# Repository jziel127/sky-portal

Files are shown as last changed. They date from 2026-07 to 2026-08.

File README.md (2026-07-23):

# Sky Portal — Automated Circadian Lighting & Clock

A personal engineering project that adds automation and a companion display to a [Chroma Sky Portal 2.1](https://getchroma.co/) circadian light — without modifying the light itself.

## What it does

- **Automates the Sky Portal's settings** (brightness/"Photon" and color temperature/"Red-White Ratio") throughout the day, driven by real solar and weather data rather than a physical light sensor. Small external servos physically turn the light's existing knobs, so the device itself is never opened or altered.
- **Auto power on/off** via a third, higher-torque servo that physically flips the unit's power switch.
- **A companion 16x16 LED matrix** running [WLED](https://kno.wled.ge/) on an ESP32 shows a clock, the date, and the current outdoor weather (with a simple animated icon and temperature), cycling automatically.

## How it works (high level)

```
Windows mini PC (central brain)
   │  pulls solar elevation + cloud cover from OpenWeatherMap
   │  computes a "circadian phase" for the day
   │
   ├── USB Serial ──► Arduino Pro Mini ──► 3 servos (Photon, Color Ratio, Power)
   │
   └── HTTP/MQTT ──► ESP32 (WLED) ──► 16x16 LED matrix (clock + weather display)
```

## Hardware

- Chroma Sky Portal 2.1 (the light being automated)
- Windows mini PC (GMK NucBox5) — control logic, API calls
- Arduino Pro Mini + FTDI adapter — servo control
- 2x SG90 micro servos + 1x MG996R servo
- ESP32 + WS2812B 16x16 LED matrix, running WLED
- Custom 3D-printed enclosure housing the electronics, attached to the light's stand

## Status

Actively in progress — the LED matrix clock is fully built and running; the servo/knob automation is the current phase of work.

## Why this project exists

Built as a personal engineering/robotics project to combine embedded systems, API integration, and mechanical design into something used every day — not a commercial product, and not affiliated with Chroma.

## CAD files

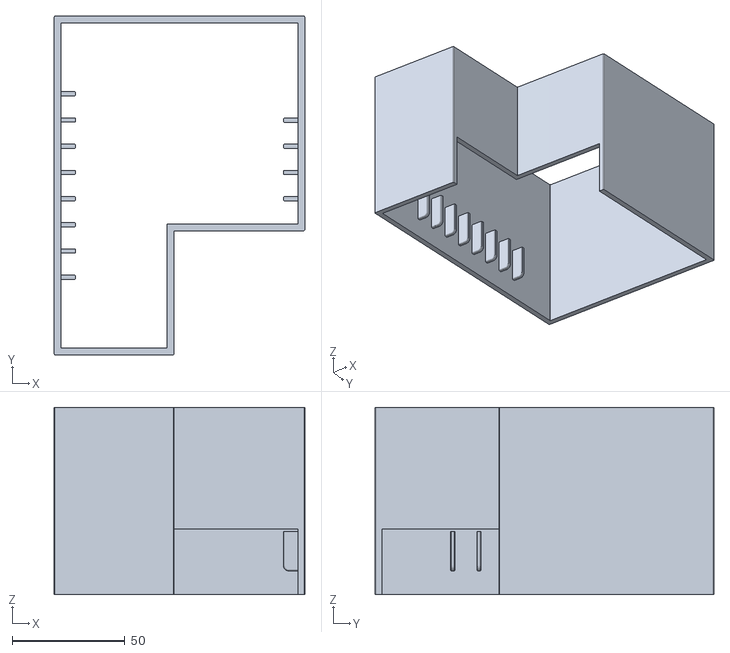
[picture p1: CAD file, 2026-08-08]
3D Models/SkyPortal Outer Case.stl
111.0 x 150.2 x 83.0

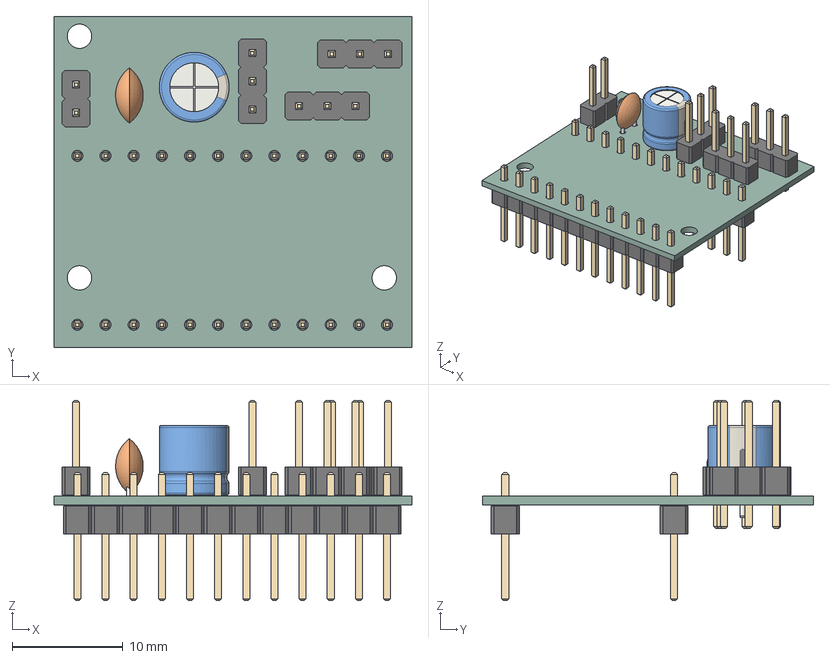
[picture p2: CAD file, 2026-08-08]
Motor PCB/MotorPCB.step
32.3 x 29.9 x 18.1 mm
CP_Radial_D63mm_P250mm
PinHeader_1x03_P254mm_Vertical x 3
PinHeader_1x02_P254mm_Vertical
C_Disc_D50mm_W25mm_P250mm
PinHeader_1x12_P254mm_Vertical x 2
Motor PCB_PCB

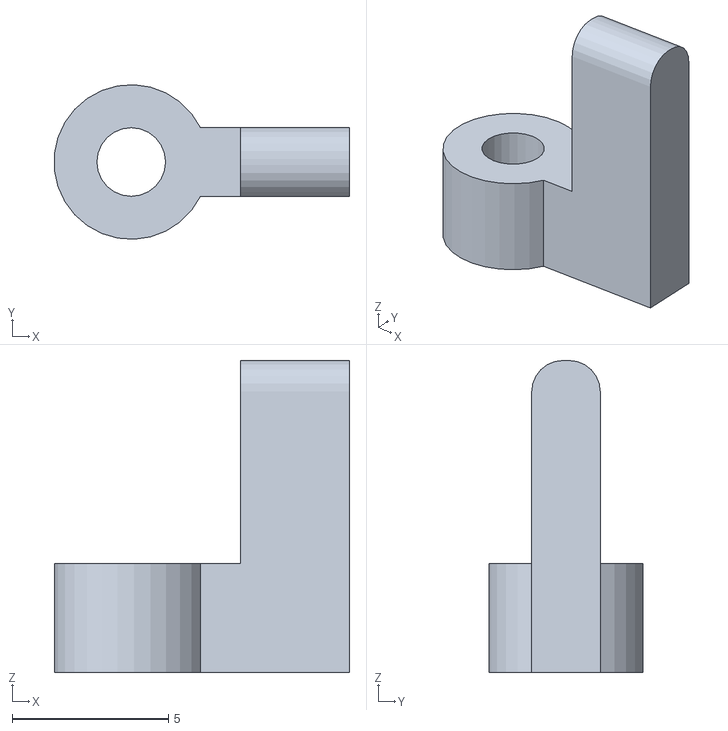
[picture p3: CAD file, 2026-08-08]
3D Models/Servo_LSmodv3.stl
9.46 x 4.95 x 10.00

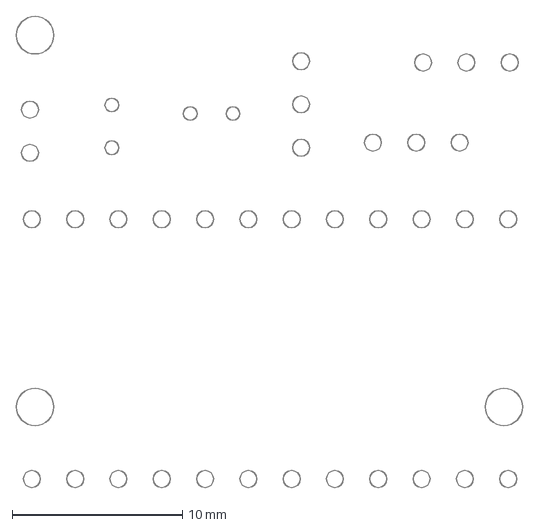
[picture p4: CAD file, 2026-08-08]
Motor PCB/Motor PCB-User_Drawings.dxf
29.7 x 27.6 mm

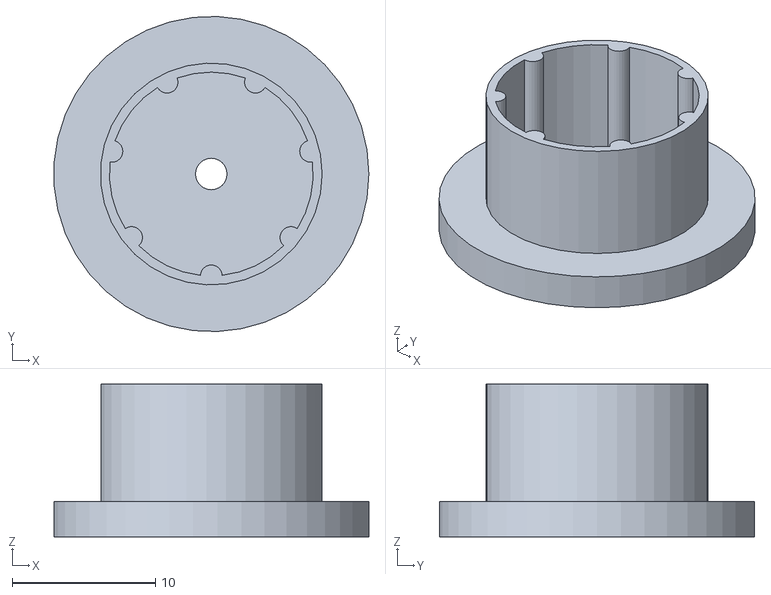
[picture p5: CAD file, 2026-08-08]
3D Models/POT_mod.STL
22.0 x 22.0 x 10.7

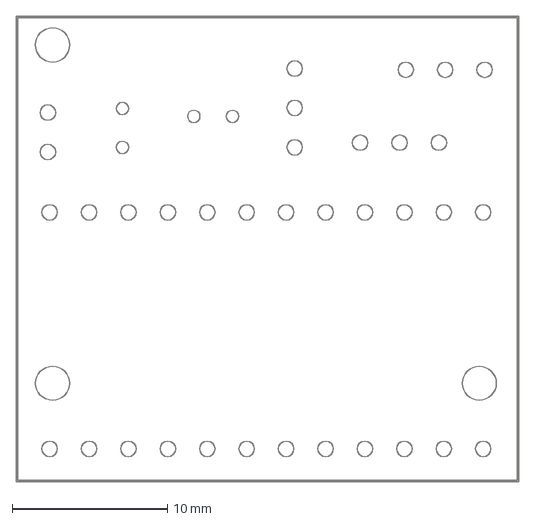
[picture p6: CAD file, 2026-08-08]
Motor PCB/Motor PCB-Edge_Cuts.dxf
32.4 x 30.0 mm

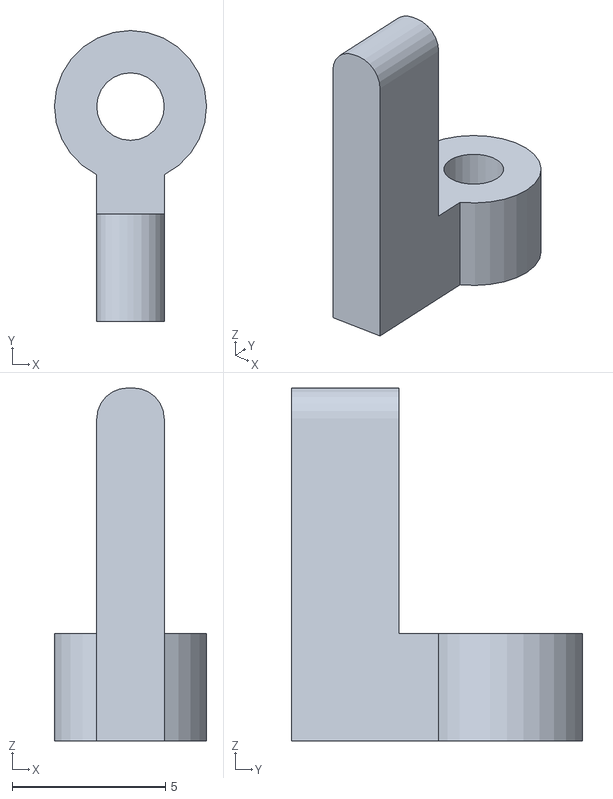
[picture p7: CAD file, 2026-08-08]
3D Models/Servo_LSmodv2.stl
4.95 x 9.48 x 11.5

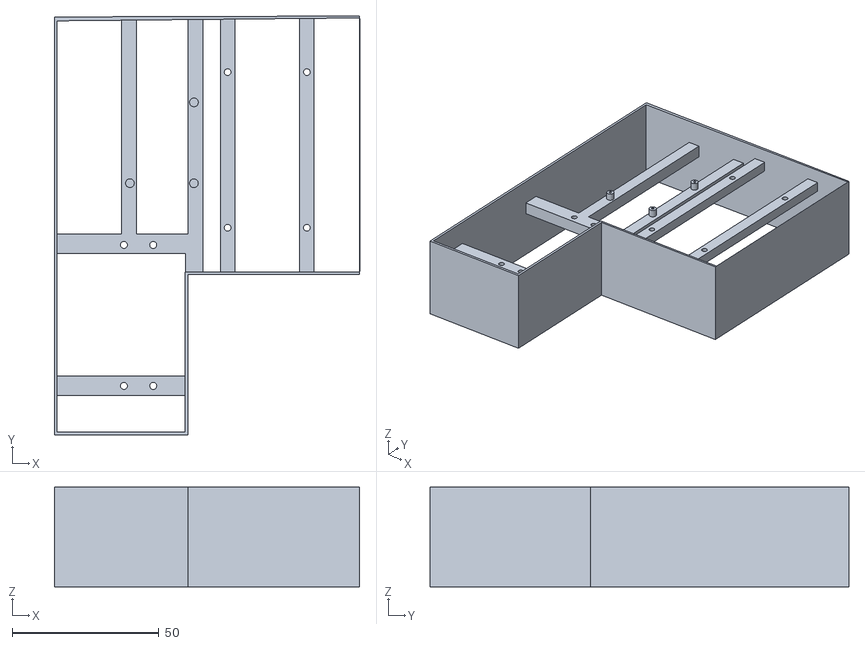
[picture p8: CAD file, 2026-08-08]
3D Models/SkyPortal Bracket.stl
104.0 x 142.7 x 34.0

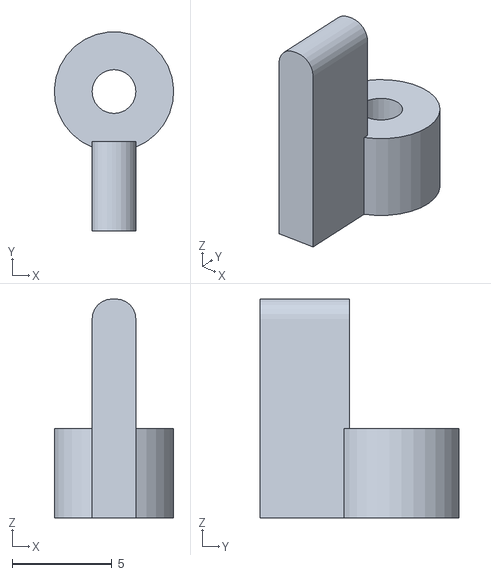
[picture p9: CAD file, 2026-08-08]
3D Models/Servo_LSmodv4.stl
6.00 x 9.98 x 11.0

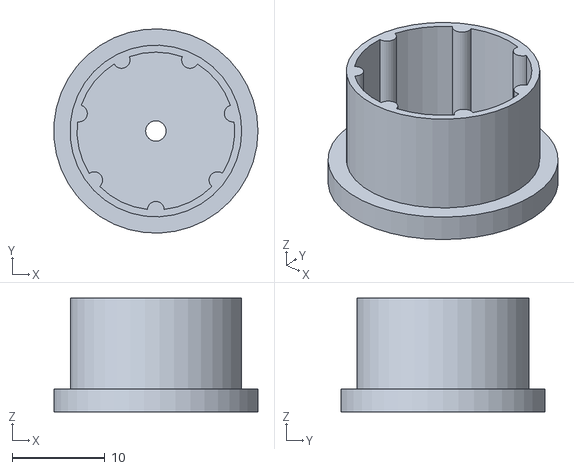
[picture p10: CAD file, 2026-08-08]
3D Models/Servo_POTmod.stl
22.0 x 22.0 x 12.3

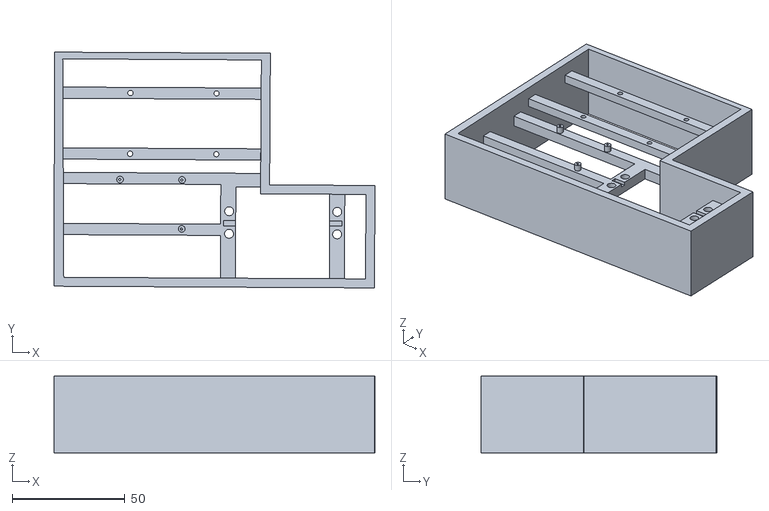
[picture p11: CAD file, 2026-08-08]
3D Models/SkyPortal PCBracket v2.stl
142.6 x 104.7 x 34.0

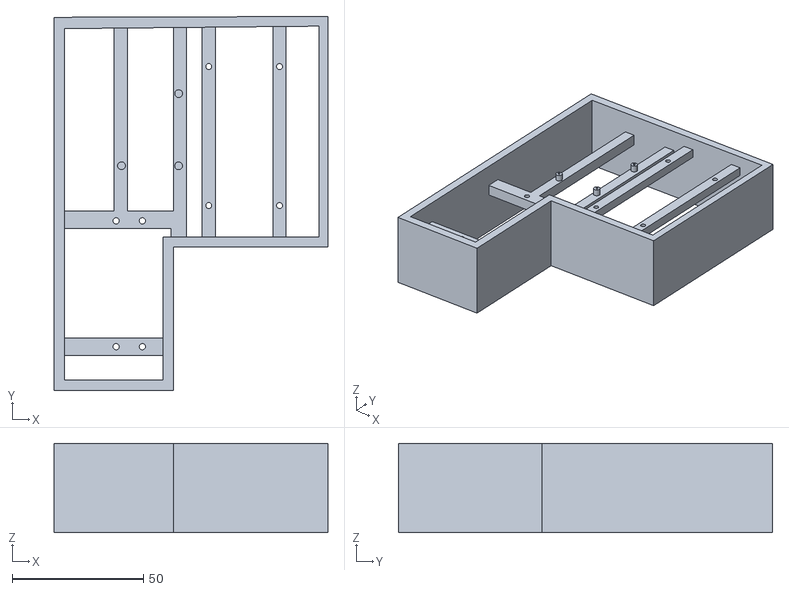
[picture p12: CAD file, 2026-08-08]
3D Models/SkyPortal Bracket v2.stl
104.5 x 142.7 x 34.0

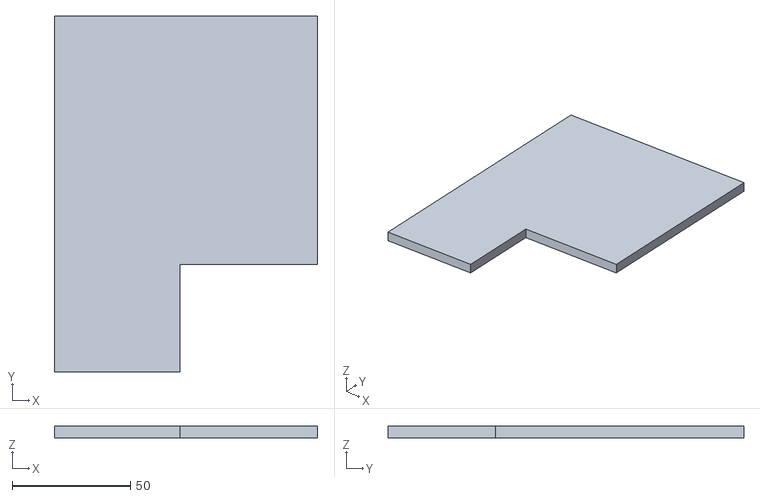
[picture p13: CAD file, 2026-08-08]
3D Models/SkyPortal cover.stl
111.1 x 150.3 x 5.00

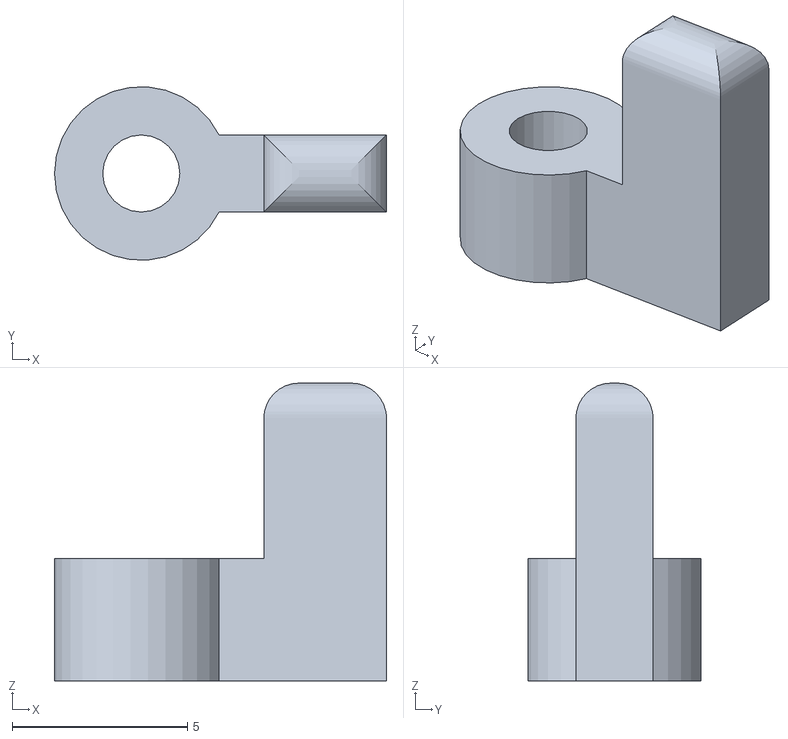
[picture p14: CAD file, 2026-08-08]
3D Models/Servo_LSmod.stl
9.48 x 4.94 x 8.50

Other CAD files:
3D Models/SkyPortal Case.dwg
3D Models/SkyPortal OuterCasev2.stl
3D Models/Servo_LSmod.dwg
3D Models/Servo_POTmod.dwg

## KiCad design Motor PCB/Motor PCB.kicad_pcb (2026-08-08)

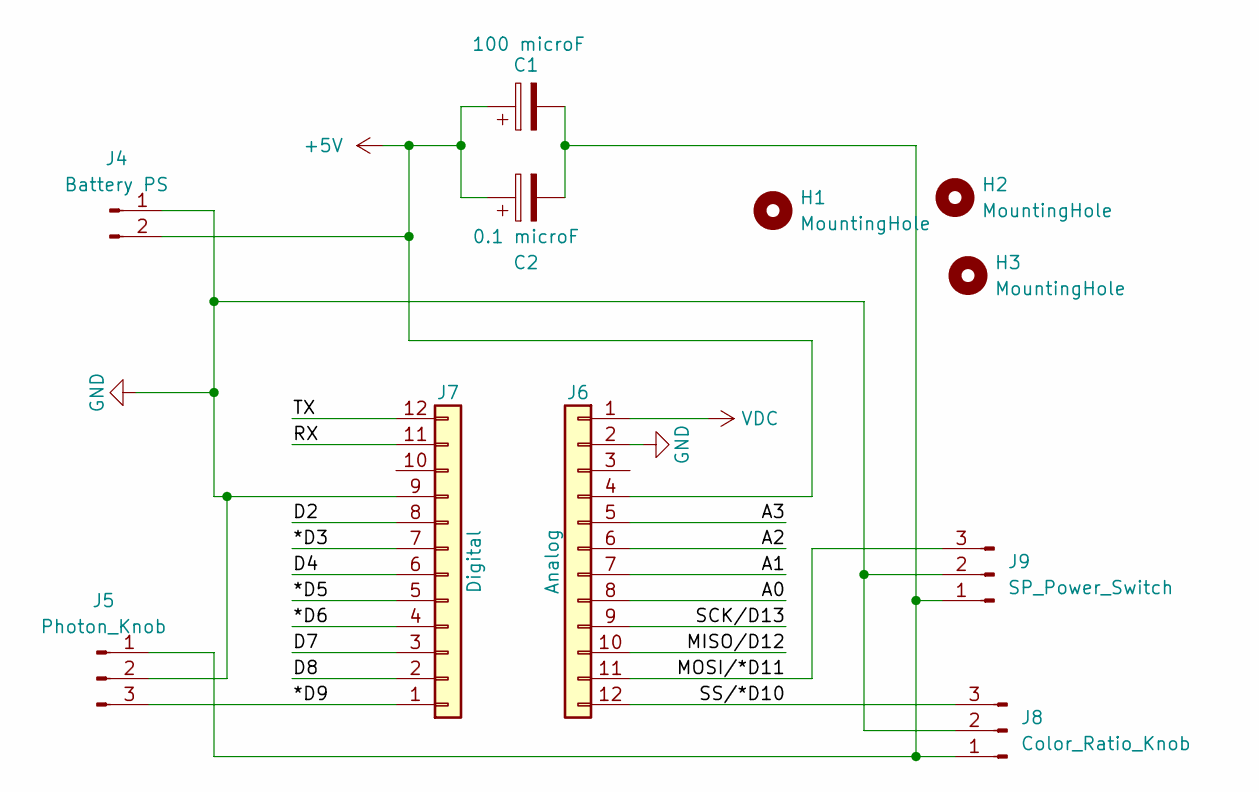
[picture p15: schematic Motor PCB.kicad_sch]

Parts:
C1: 100 microF; CP_Radial_D6.3mm_P2.50mm
C2: 0.1 microF; C_Disc_D5.0mm_W2.5mm_P2.50mm
H1, H2, H3: MountingHole; MountingHole_2.2mm_M2
J4: Battery PS; PinHeader_1x02_P2.54mm_Vertical
J5: Photon_Knob; PinHeader_1x03_P2.54mm_Vertical
J6: Analog; PinHeader_1x12_P2.54mm_Vertical
J7: Digital; PinHeader_1x12_P2.54mm_Vertical
J8: Color_Ratio_Knob; PinHeader_1x03_P2.54mm_Vertical
J9: SP_Power_Switch; PinHeader_1x03_P2.54mm_Vertical

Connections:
+5V: C1.1, C2.1, J4.2, J6.4
/*D3: J7.7
/*D5: J7.5
/*D6: J7.4
/*D9: J5.3, J7.1
/A0: J6.8
/A1: J6.7
/A2: J6.6
/A3: J6.5
/D2: J7.8
/D4: J7.6
/D7: J7.3
/D8: J7.2
/MISO/D12: J6.10
/MOSI/*D11: J6.11, J9.3
/RX: J7.11
/SCK/D13: J6.9
/SS/*D10: J6.12, J8.3
/TX: J7.12
GND: J4.1, J5.2, J6.2, J7.9, J8.2, J9.2
unnamed: C1.2, C2.2, J5.1, J8.1, J9.1
VDC: J6.1

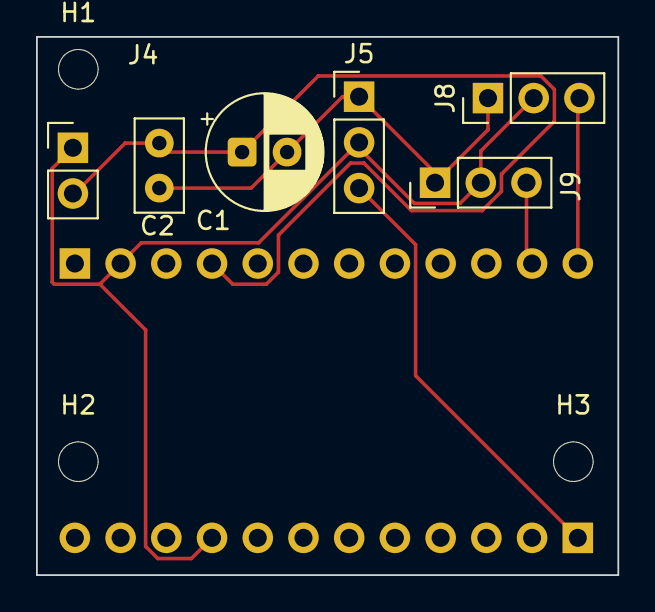
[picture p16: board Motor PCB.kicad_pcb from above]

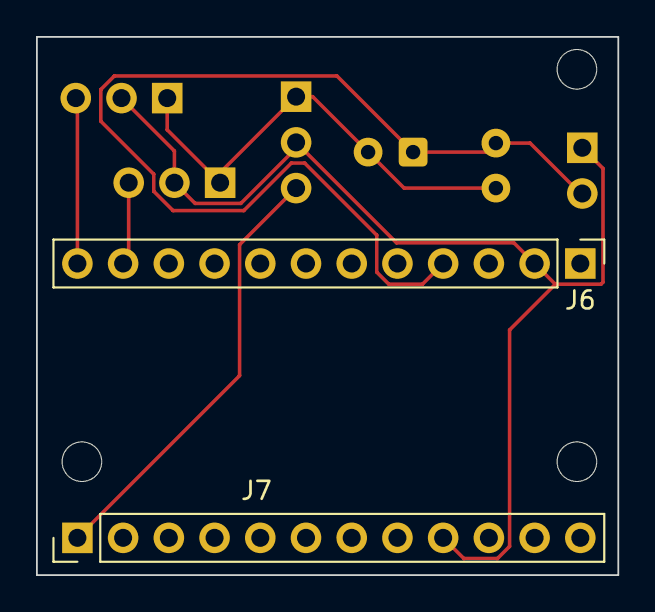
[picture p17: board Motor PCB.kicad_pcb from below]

Board: 2 copper layers, 32.3 x 29.9 mm, 11 parts (2 on the bottom side), 6 nets.

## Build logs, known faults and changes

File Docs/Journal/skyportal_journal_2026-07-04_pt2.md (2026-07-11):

# Sky Portal Project — Journal Entry (Part 2)
**Date:** July 4, 2026 (continued)
**Session focus:** Architecture simplification (weather-API-driven, no physical light sensor), WLED/ESP32 decision, comprehensive status check

---

## Major Architecture Decision: No Physical Light Sensor

**Change:** Dropped the BH1750 ambient light sensor and the Pico W's role as a wireless sensor node. Circadian logic will be driven **entirely by OpenWeatherMap API data** (solar elevation, cloud cover, UV index) rather than fused with real-world lux readings.

**Why:** Simpler build, no sensor hardware to buy/mount near a window, one less wireless node to maintain.

**What this eliminates:**
- BH1750 sensor (no longer needed)
- Pico W's original job (reading BH1750, publishing lux over MQTT) — no longer needed
- Sensor fusion logic in the circadian-phase calculation — simplified to weather-data-only

**What survives from that work:**
- Mosquitto broker — kept running, will be used for the future tablet control panel (final project phase)
- Pico W hardware itself — currently idle, may be repurposed (see WLED/ESP32 section below)
- All infrastructure debugging from today (static IP, Python env, VS Code/MicroPico, Mega serial) — general-purpose, not wasted

---

## WLED / ESP32 Decision (LED Matrix Control)

**Trigger:** Found a YouTube video ("16x16 LED Matrix Setup with WLED and ESP32, BEST Enclosure Design") demonstrating WLED firmware + ESP32 + a 3D-printed enclosure for a 16x16 WS2812B matrix — directly applicable to the Sky Portal desk display.

**Investigated:** Whether the already-owned Raspberry Pi Pico W could run WLED instead of buying new hardware.

**Finding:** WLED does **not** officially support the Pico W / RP2040 chip. Two separate feature requests for RP2040 support were formally closed by WLED maintainers as "not planned." WLED is built specifically for ESP8266/ESP32 (Espressif) chips.

**Decision:** Acquired the same ESP32 board used in the referenced video, specifically to run WLED for the LED matrix. Pico W remains idle/unused for now (available for future repurposing if needed).

### Updated Hardware Roles

| Component | Role |
|---|---|
| Windows Mini PC (NucBox5) | Central brain — OpenWeatherMap API calls, circadian phase calculation, sends commands via serial (to Mega) and MQTT/HTTP (to WLED on ESP32) |
| ESP32 (new) | Runs WLED firmware, drives the WS2812B 16x16 matrix, controlled via WLED's built-in JSON API / MQTT |
| Elegoo Mega 2560 | Drives the 2x SG90 servos (Sky Portal knob control) via USB serial from the mini PC — confirmed working (Leg 2 test) |
| Raspberry Pi Pico W | Currently idle — MQTT pipeline proven working, could be repurposed later if a wireless sensor or other node is ever added back |
| Mosquitto (on mini PC) | Broker kept running — reserved for future tablet control panel (final phase) and potentially for WLED's MQTT interface |

### Revised Data Flow

```
[Windows Mini PC — NucBox5]
    │ OpenWeatherMap API → circadian phase calculation
    │
    ├── USB Serial (pyserial) ──→ Elegoo Mega 2560 ──→ 2x SG90 servos ──→ Sky Portal knobs
    │
    └── MQTT / HTTP JSON API ──→ ESP32 (WLED) ──→ WS2812B 16x16 matrix
```

---

## Physical Build Status

- **3D printing in progress** for enclosure/mounting parts (following the design referenced in the WLED video) — estimated **~1 more day** until all parts are done
- **Known issue flagged:** trouble with the **back plate** during printing — not yet resolved/detailed; to be revisited if it recurs. Noting here so it isn't lost track of.

---

## Comprehensive Status Check — All Systems

| System | Status | Notes |
|---|---|---|
| Windows Mini PC networking | ✅ Done | Static IP `192.168.1.222`, gateway `192.168.1.254`, DNS `8.8.8.8`/`1.1.1.1`, Private network profile confirmed |
| Python environment | ✅ Done | Installed and working after installer/service hiccups |
| Mosquitto broker | ✅ Done | Listening on `0.0.0.0:1883` (fixed from localhost-only), firewall rule allowed, service confirmed running |
| VS Code + MicroPico | ✅ Done | Extension installed, Pico W firmware flashed, vREPL working |
| Arduino IDE + Mega 2560 | ✅ Done | Flashed, serial confirmed on COM3 |
| **Leg 1: Mosquitto loopback** | ✅ Confirmed | pub/sub tested locally |
| **Leg 2: Mega ↔ Python serial** | ✅ Confirmed | LED_ON test successful — this is the leg that matters going forward (servo control) |
| **Leg 3: Pico W → MQTT** | ✅ Confirmed | Full Wi-Fi → broker → subscriber chain validated (0–12 counter test) — pipeline proven, though Pico W's original job (sensor) is no longer part of the plan |
| BH1750 sensor | ❌ Not used | Architecture decision — using weather API instead |
| Circadian-phase Python script | ⬜ Not started | Next major software task |
| Mega servo control sketch | ⬜ Not started | Replace LED test sketch with real SG90 PWM code |
| ESP32 + WLED setup | ⬜ Not started | New hardware just acquired |
| Windows Scheduled Task | ⬜ Deferred | Waiting until control script exists |
| Tablet control panel | 🔜 Final phase | Explicitly deferred until core automation is finished; budget tablet options already researched (Fire HD 8, Galaxy Tab A8/A9, Lenovo Tab M10/M11) |

---

## To-Do List — Next Moves

### Immediate (while waiting on 3D prints, ~1 day)
1. [ ] Set up OpenWeatherMap API account/key if not already done
2. [ ] Flash WLED firmware onto the new ESP32 (via WLED's web installer or esptool)
3. [ ] Confirm ESP32 connects to Wi-Fi and WLED's web UI is reachable
4. [ ] Test WLED's JSON API / MQTT interface with simple manual commands (set color, brightness) before writing any control code
5. [ ] Revisit the back plate 3D print issue if it recurs — flag specifics (warping, layer separation, fitment, etc.) once seen again

### Once 3D prints are done
6. [ ] Physically mount ESP32 + WS2812B matrix using the printed enclosure
7. [ ] Mount SG90 servos onto Sky Portal knobs (Photon + Red/White Ratio)

### Core software build (can start in parallel with printing)
8. [ ] Write the circadian-phase Python script on the mini PC:
   - Pull solar elevation, cloud cover, UV index from OpenWeatherMap
   - Convert to photon level (0–100%) and color-temp ratio (0–100%)
9. [ ] Write the real Mega sketch: replace LED test code with SG90 servo PWM control, driven by serial commands from the Python script
10. [ ] Write the WLED control layer: Python script sends JSON API or MQTT commands to the ESP32 to update matrix color/brightness in sync with circadian phase
11. [ ] Integrate all three pieces into one continuous control loop on the mini PC
12. [ ] Set up the Windows Scheduled Task to run the finished script automatically at startup

### Final phase (explicitly deferred)
13. [ ] Tablet control panel — build a simple web dashboard (Flask or similar) for manual override, served from the mini PC, controlled via MQTT; select tablet hardware from previously researched options

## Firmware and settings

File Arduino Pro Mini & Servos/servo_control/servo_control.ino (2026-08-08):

#include <Servo.h>
#include <EEPROM.h>

// --- PCB PIN DEFINITIONS ---
const int PIN_PHOTON       = 9;   // J5 Header
const int PIN_COLOR_RATIO  = 10;  // J8 Header
const int PIN_POWER_SWITCH = 11;  // J9 Header

// --- EEPROM ADDRESSES ---
const int ADDR_PHOTON       = 0;
const int ADDR_COLOR_RATIO  = 2;
const int ADDR_POWER_SWITCH = 4;
const int ADDR_MAGIC        = 6;  // Marker to check if EEPROM is initialized
const uint16_t EEPROM_MAGIC = 0xABCD;

// --- SERVO OBJECTS & STATE ---
Servo photonServo;
Servo colorRatioServo;
Servo powerServo;

int targetPhoton     = 0;   // 0 (Max Red) to 180 (White)
int targetColorRatio = 0;   // 0 (Low) to 180 (High)
int targetPower      = 0;   // 0 (OFF) to 180 (ON)

int currentPhoton     = 0;
int currentColorRatio = 0;
int currentPower      = 0;

// --- HELPER: SMOOTH MOTION ENGINE ---
// Moves servos incrementally to eliminate harsh mechanical snaps and current spikes
void moveServosSmoothly() {
  bool moving = true;
  while (moving) {
    moving = false;

    // Photon Knob
    if (currentPhoton < targetPhoton) { currentPhoton++; moving = true; }
    else if (currentPhoton > targetPhoton) { currentPhoton--; moving = true; }
    photonServo.write(currentPhoton);

    // Color Ratio Knob
    if (currentColorRatio < targetColorRatio) { currentColorRatio++; moving = true; }
    else if (currentColorRatio > targetColorRatio) { currentColorRatio--; moving = true; }
    colorRatioServo.write(currentColorRatio);

    // Light Power Switch
    if (currentPower < targetPower) { currentPower++; moving = true; }
    else if (currentPower > targetPower) { currentPower--; moving = true; }
    powerServo.write(currentPower);

    delay(10); // Adjust step speed (lower = faster movement)
  }
}

// --- HELPER: SAVE STATE TO EEPROM ---
void saveState() {
  EEPROM.put(ADDR_PHOTON, targetPhoton);
  EEPROM.put(ADDR_COLOR_RATIO, targetColorRatio);
  EEPROM.put(ADDR_POWER_SWITCH, targetPower);
  EEPROM.put(ADDR_MAGIC, EEPROM_MAGIC);
}

// --- HELPER: LOAD STATE FROM EEPROM ---
void loadState() {
  uint16_t magic;
  EEPROM.get(ADDR_MAGIC, magic);

  if (magic == EEPROM_MAGIC) {
    EEPROM.get(ADDR_PHOTON, targetPhoton);
    EEPROM.get(ADDR_COLOR_RATIO, targetColorRatio);
    EEPROM.get(ADDR_POWER_SWITCH, targetPower);

    // Sanity bounds check
    targetPhoton     = constrain(targetPhoton, 0, 180);
    targetColorRatio = constrain(targetColorRatio, 0, 180);
    targetPower      = constrain(targetPower, 0, 180);
  } else {
    // Default values if first boot
    targetPhoton     = 0;   // High Red
    targetColorRatio = 0;   // Low Photon
    targetPower      = 0;   // OFF
    saveState();
  }

  currentPhoton     = targetPhoton;
  currentColorRatio = targetColorRatio;
  currentPower      = targetPower;
}

// --- TELEMETRY & STATUS PRINT ---
void printStatus() {
  Serial.println(F("\n--- SKYPORTAL SYSTEM STATUS ---"));
  
  Serial.print(F("Power Switch (D11): "));
  Serial.print(targetPower);
  Serial.println(targetPower >= 90 ? F("° [ON]") : F("° [OFF]"));

  Serial.print(F("Photon Knob  (D9) : "));
  Serial.print(targetPhoton);
  Serial.println(F("° (0=Red, 180=White)"));

  Serial.print(F("Color Ratio  (D10): "));
  Serial.print(targetColorRatio);
  Serial.println(F("° (0=Low, 180=High)"));
  
  Serial.println(F("-------------------------------\n"));
}

void printHelp() {
  Serial.println(F("=== SKYPORTAL CONTROL COMMANDS ==="));
  Serial.println(F("  PWR <0 or 180>     -> Toggle Power Switch (0=OFF, 180=ON)"));
  Serial.println(F("  PHO <0-180>        -> Set Photon Knob Angle"));
  Serial.println(F("  COL <0-180>        -> Set Color Ratio Knob Angle"));
  Serial.println(F("  SET <pwr> <pho> <col> -> Set all 3 parameters at once"));
  Serial.println(F("  STATUS             -> Display system state"));
  Serial.println(F("=================================="));
}

void setup() {
  Serial.begin(9600);
  delay(500);

  // 1. Load persisted state from non-volatile memory
  loadState();

  // 2. Pre-set servo positions BEFORE attaching to prevent startup snap
  photonServo.write(currentPhoton);
  colorRatioServo.write(currentColorRatio);
  powerServo.write(currentPower);

  // 3. Attach hardware PWM pins
  photonServo.attach(PIN_PHOTON);
  colorRatioServo.attach(PIN_COLOR_RATIO);
  powerServo.attach(PIN_POWER_SWITCH);

  Serial.println(F("SkyPortal Prototype Online. Memory restored."));
  printStatus();
  printHelp();
}

void loop() {
  if (Serial.available() > 0) {
    String input = Serial.readStringUntil('\n');
    input.trim();
    input.toUpperCase();

    if (input == "STATUS") {
      printStatus();
    } 
    else if (input.startsWith("PWR ")) {
      int val = input.substring(4).toInt();
      targetPower = (val >= 90) ? 180 : 0;
      moveServosSmoothly();
      saveState();
      printStatus();
    } 
    else if (input.startsWith("PHO ")) {
      int val = input.substring(4).toInt();
      targetPhoton = constrain(val, 0, 180);
      moveServosSmoothly();
      saveState();
      printStatus();
    } 
    else if (input.startsWith("COL ")) {
      int val = input.substring(4).toInt();
      targetColorRatio = constrain(val, 0, 180);
      moveServosSmoothly();
      saveState();
      printStatus();
    }
    else if (input.startsWith("SET ")) {
      // Parse multi-argument command: SET <pwr> <pho> <col>
      int space1 = input.indexOf(' ', 4);
      int space2 = input.indexOf(' ', space1 + 1);
      
      if (space1 > 0 && space2 > 0) {
        int pwr = input.substring(4, space1).toInt();
        int pho = input.substring(space1 + 1, space2).toInt();
        int col = input.substring(space2 + 1).toInt();

        targetPower      = (pwr >= 90) ? 180 : 0;
        targetPhoton     = constrain(pho, 0, 180);
        targetColorRatio = constrain(col, 0, 180);

        moveServosSmoothly();
        saveState();
        printStatus();
      }
    } 
    else {
      printHelp();
    }
  }
}

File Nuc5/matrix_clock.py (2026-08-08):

"""
Sky Portal - LED Matrix Clock (v16 - Shifted Temp Alignment)
------------------------------------------------------------
- Shifted temperature reading 1px left (starting at col 8) for clean margins.
- Bottom Weather View: Animated Icon (Left) + Live Temperature (Right).
- Bottom Date View: Solid cycling slides (MONTH -> DATE -> DAY).
"""

import sys
import os

# Guarantee Nuc5 directory is in sys.path BEFORE importing config
SCRIPT_DIR = os.path.dirname(os.path.abspath(__file__))
if SCRIPT_DIR not in sys.path:
    sys.path.insert(0, SCRIPT_DIR)

import requests
import time
from datetime import datetime

try:
    from config import API_KEY, LAT, LON, WLED_IP
except ImportError:
    print("[MATRIX WARN] Could not import config.py - using fallbacks.")
    API_KEY = "YOUR_API_KEY_HERE"
    LAT, LON = 43.13, -88.22
    WLED_IP = "192.168.1.209"

MATRIX_WIDTH = 16
MATRIX_HEIGHT = 16
ORIENTATION = "rotate_ccw_then_flip_v"

# Palette
CLOCK_COLOR = (255, 140, 0)     # Warm Orange
BORDER_COLOR = (180, 80, 0)     # Warm Amber
DIVIDER_COLOR = (60, 60, 60)    # Soft Gray

TEMP_REFRESH_SECONDS = 15 * 60
VIEW_SWAP_SECONDS = 10          
MAIN_LOOP_TICK = 0.20

# ---------------- 3x5 Font Engine ----------------

FONT_3x5 = {
    "0": ["111", "101", "101", "101", "111"],
    "1": ["010", "110", "010", "010", "111"],
    "2": ["111", "001", "111", "100", "111"],
    "3": ["111", "001", "111", "001", "111"],
    "4": ["101", "101", "111", "001", "001"],
    "5": ["111", "100", "111", "001", "111"],
    "6": ["111", "100", "111", "101", "111"],
    "7": ["111", "001", "001", "001", "001"],
    "8": ["111", "101", "111", "101", "111"],
    "9": ["111", "101", "111", "001", "111"],
    "A": ["010", "101", "111", "101", "101"],
    "B": ["110", "101", "110", "101", "110"],
    "C": ["011", "100", "100", "100", "011"],
    "D": ["110", "101", "101", "101", "110"],
    "E": ["111", "100", "110", "100", "111"],
    "F": ["111", "100", "110", "100", "100"],
    "G": ["011", "100", "101", "101", "011"],
    "H": ["101", "101", "111", "101", "101"],
    "I": ["111", "010", "010", "010", "111"],
    "J": ["001", "001", "001", "101", "010"],
    "K": ["101", "101", "110", "101", "101"],
    "L": ["100", "100", "100", "100", "111"],
    "M": ["101", "111", "101", "101", "101"],
    "N": ["101", "111", "111", "101", "101"],
    "O": ["010", "101", "101", "101", "010"],
    "P": ["111", "101", "111", "100", "100"],
    "Q": ["010", "101", "101", "110", "011"],
    "R": ["110", "101", "110", "101", "101"],
    "S": ["011", "100", "010", "001", "110"],
    "T": ["111", "010", "010", "010", "010"],
    "U": ["101", "101", "101", "101", "011"],
    "V": ["101", "101", "101", "101", "010"],
    "W": ["101", "101", "101", "111", "101"],
    "X": ["101", "101", "010", "101", "101"],
    "Y": ["101", "101", "010", "010", "010"],
    "Z": ["111", "001", "010", "100", "111"],
    "-": ["000", "000", "111", "000", "000"],
    " ": ["000", "000", "000", "000", "000"],
}

# --- Weather Bitmaps ---

MOON_BODY_BITMAP = [
    "001000",
    "010000",
    "011010",
    "001100"
]

CLOUD_BITMAP = [
    "000000",
    "001100",
    "011110",
    "000000"
]

ICON_FRAMES = {
    "sun": [
        ["001100", "011110", "011110", "001100"]
    ],
    "rain": [
        ["011100", "111111", "010010", "000000"],
        ["011100", "111111", "000000", "010010"],
    ],
    "snow": [
        ["010000", "000010", "001000", "100001"],
        ["000010", "010000", "100001", "001000"],
    ],
}

ICON_COLORS = {
    "sun": (255, 200, 0),
    "moon": (180, 220, 255),
    "cloud": (170, 170, 190),
    "rain": (60, 120, 220),
    "snow": (210, 240, 255),
}

STAR_COLOR_CYCLE = [
    (100, 240, 255),  # Cyan
    (180, 180, 255),  # Soft Violet
    (255, 220, 120),  # Warm Gold
    (255, 255, 255),  # Pure White
]

CONDITION_TO_ICON = {
    "Clear": "sun",
    "Clouds": "cloud",
    "Rain": "rain",
    "Drizzle": "rain",
    "Thunderstorm": "rain",
    "Snow": "snow",
    "Mist": "cloud",
    "Fog": "cloud",
    "Haze": "cloud",
}

# ---------------- Drawing Helpers ----------------

def draw_bitmap(grid, rows, x_offset, y_offset, color):
    for row_idx, row in enumerate(rows):
        for col_idx, px in enumerate(row):
            if px == "1":
                x, y = x_offset + col_idx, y_offset + row_idx
                if 1 <= x < (MATRIX_WIDTH - 1) and 0 <= y < MATRIX_HEIGHT:
                    grid[y][x] = color


def draw_pixel(grid, x, y, color):
    if 1 <= x < (MATRIX_WIDTH - 1) and 0 <= y < MATRIX_HEIGHT:
        grid[y][x] = color


def draw_border(grid, color):
    for x in range(MATRIX_WIDTH):
        grid[0][x] = color
        grid[MATRIX_HEIGHT - 1][x] = color
    for y in range(MATRIX_HEIGHT):
        grid[y][0] = color
        grid[y][MATRIX_WIDTH - 1] = color


def draw_centered_text(grid, text, y_offset, color):
    text = text.upper()
    total_px = (len(text) * 3) + (len(text) - 1)
    x_start = (MATRIX_WIDTH - total_px) // 2

    curr_x = x_start
    for ch in text:
        if ch in FONT_3x5:
            draw_bitmap(grid, FONT_3x5[ch], curr_x, y_offset, color)
        curr_x += 4


def transform_coords(x, y, mode):
    n = MATRIX_WIDTH
    if mode == "rotate_ccw_then_flip_v":
        xr, yr = y, n - 1 - x
        return xr, n - 1 - yr
    return x, y


# ---------------- Weather Cache ----------------

_weather_cache = {"temp": None, "icon": "cloud", "fetched_at": 0}


def get_weather(session):
    now = time.time()
    if _weather_cache["temp"] is not None and (now - _weather_cache["fetched_at"]) < TEMP_REFRESH_SECONDS:
        return _weather_cache["temp"], _weather_cache["icon"]
    try:
        url = (
            f"https://api.openweathermap.org/data/2.5/weather"
            f"?lat={LAT}&lon={LON}&appid={API_KEY}&units=imperial"
        )
        resp = session.get(url, timeout=8)
        resp.raise_for_status()
        data = resp.json()
        temp = round(data["main"]["temp"])
        condition = data["weather"][0]["main"]

        hour = datetime.now().hour
        if condition == "Clear":
            icon = "sun" if (6 <= hour < 21) else "moon"
        else:
            icon = CONDITION_TO_ICON.get(condition, "cloud")

        _weather_cache.update(temp=temp, icon=icon, fetched_at=now)
        return temp, icon
    except Exception as e:
        print(f"[MATRIX WEATHER ERR] {e}")
        return _weather_cache["temp"], _weather_cache["icon"]


# ---------------- Display Rendering ----------------

def draw_clock(grid):
    now = datetime.now()
    hh, mm = now.strftime("%H"), now.strftime("%M")
    y_offset = 1
    draw_bitmap(grid, FONT_3x5[hh[0]], 1, y_offset, CLOCK_COLOR)
    draw_bitmap(grid, FONT_3x5[hh[1]], 4, y_offset, CLOCK_COLOR)
    draw_bitmap(grid, FONT_3x5[mm[0]], 9, y_offset, CLOCK_COLOR)
    draw_bitmap(grid, FONT_3x5[mm[1]], 12, y_offset, CLOCK_COLOR)


def draw_zigzag(grid):
    for x in range(1, 15):
        row = 7 if x % 2 == 0 else 8
        grid[row][x] = DIVIDER_COLOR
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
